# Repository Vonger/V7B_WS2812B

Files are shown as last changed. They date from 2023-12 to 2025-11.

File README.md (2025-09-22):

### Compile Firmware
1. download wch riscv toolchain from its offical site(http://www.mounriver.com/download, select Linux).
2. call **make** to compile the firmware.
3. call **make flash** to upload firmware to device.(hardware requires WCH-LinkE, PD1 to SWDIO)
4. call **make test** to create the local test application.
5. run test, check result on dashboard.

note: IS31FL3731 compatible mode register address only use 1bytes, so max supported LEDs are 72 RGB LEDs(or 216 single color LEDs). Not compatible mode has two bytes for address, so max supported LEDs are 512 RGB LEDs or more(depends on the memory to buffer the LED data)

- ws2812b.is31.bin: this is compatible IS31FL3731 firmware.
- ws2812b.full.bin: this is not compatible but can use all ws2812b in line firmware.

### Link

 - Compile in Ubuntu 22.04
 - WCH CH32V003 RISCV toolchain: http://www.mounriver.com/download => Linux => MRS_Toolchain_Linux_x64_VX.XX.tar.xz
 - install libjlink0 for openocd(sudo apt install libjlink0).

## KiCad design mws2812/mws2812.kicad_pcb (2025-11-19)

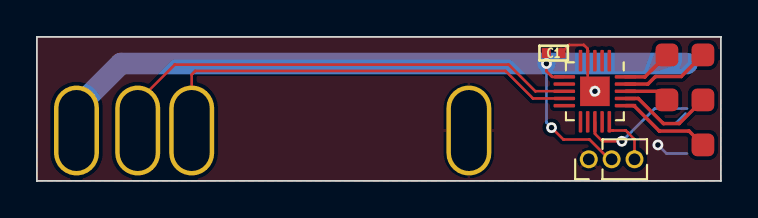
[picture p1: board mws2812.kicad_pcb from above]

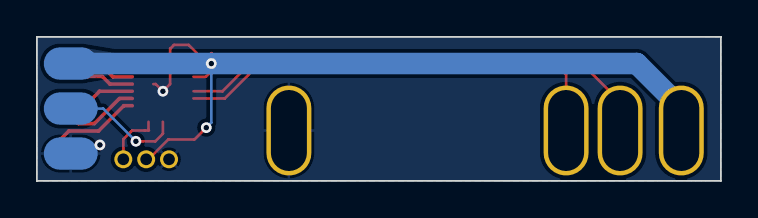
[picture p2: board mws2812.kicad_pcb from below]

Board: 2 copper layers, 38.0 x 8.0 mm, 15 parts (7 on the bottom side), 11 nets.

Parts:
C1: 100nF; 0402C
J1: Conn_01x01; TestPoint_Hole_4.0x2.0mm
J2: Conn_01x03_Socket; PinHeader_1x03_P1.27mm_Vertical
J3, J4, J5: Conn_01x01; TestPoint_Pad_3.0x2.0mm
J6, J7, J8: Conn_01x01; TestPoint_Hole_5.0x2.5mm
J9, J10, J11, J12, J13: Conn_01x01_Socket; TestPoint_Pad_D1.0mm
U3: CH32V003F4U6; QFN-20-1EP_3x3mm_P0.4mm_EP1.65x1.65mm

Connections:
+5V: C1.1, J1.1, J2.2, J5.1, U3.6 (VDD)
DEBUG: J2.3, U3.15 (PD1)
DOUT: J4.1, U3.13 (PC6)
GND: C1.2, J2.1, J3.1, J8.1, U3.4 (VSS), U3.21 (GND)
PD2: J9.1, U3.16 (PD2)
PD3: J10.1, U3.17 (PD3)
PD4: J11.1, U3.18 (PD4)
PD5: J12.1, U3.19 (PD5)
PD6: J13.1, U3.20 (PD6)
SCK: J7.1, U3.9 (PC2)
SDA: J6.1, U3.8 (PC1)

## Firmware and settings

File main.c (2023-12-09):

#include <stdint.h>
#include <ch32v00x.h>

// IS31FL3731_COMPATIBLE:
//     this mode uses 8bit reg address, allows pages(but ignores them)
//     and is compatible with IS31FL3731 register of LED colors.

// convert one 8bit to 32bits.
// 0 code 0.33us/H, 1us/L, 0x08/0b1000
// 1 code 0.66us/H, 0.66us/L, 0x0c/0b1100
// reset 50us/L, 160bits, 50 bytes of SPI around 120us.
#define SPI_RESET_COUNT     50

#ifdef IS31FL3731_COMPATIBLE
#define I2C_ADDRESS         0x74
#define WS2812_MAX_LEDS     72
volatile static uint8_t i2c_page;
#else
#define I2C_ADDRESS         0x74
#define WS2812_MAX_LEDS     512
#endif

volatile static uint8_t cid = SPI_RESET_COUNT;
volatile static uint16_t pid;
volatile static uint8_t pixel[WS2812_MAX_LEDS * 3];
volatile static uint16_t i2c_flag, i2c_reg;
const uint8_t pixel_map[4] = {0x88, 0x8c, 0xc8, 0xcc};

INTERRUPT void SPI1_IRQHandler(void)
{
    if (SPI_I2S_GetITStatus(SPI1, SPI_I2S_IT_TXE)) {
        // color id range [0:3]: we send color by bit.
        // color id range [4:84]: we send zero only as reset.
        if (cid < 4) {
            SPI1->DATAR = pixel_map[(pixel[pid] >> (cid << 1)) & 3];

            // one color has send to end, move to next color.
            if (cid == 0) {
                // if exceed the array size, turn back to begin of the pixels.
                if (++pid >= sizeof(pixel)) {
                    pid = 0;
                    // we need to send reset to leds to show colors.
                    cid = SPI_RESET_COUNT;
                } else {
                    // rearm the color id to send next color.
                    cid = 4;
                }
            }
        } else {
            // reset mode, we send two 0 bits only.
            SPI1->DATAR = 0;
        }

        cid--;
    }
}

INTERRUPT void I2C1_EV_IRQHandler(void)
{
    if (I2C_GetFlagStatus(I2C1, I2C_FLAG_ADDR)) {
        (volatile void)(I2C1->STAR2); // read to clear flag.
        // get address, new transfer begin.
        i2c_reg = i2c_flag = 0;
    } else if (I2C_GetFlagStatus(I2C1, I2C_FLAG_RXNE)) {
#ifdef IS31FL3731_COMPATIBLE
        if (i2c_flag == 0) {
            i2c_reg = I2C_ReceiveData(I2C1);
            i2c_flag++;
        } else if(i2c_reg == 0xfd) {
            i2c_page = I2C_ReceiveData(I2C1);
        } else if (i2c_page == 0) {
            // WS2812 is GRB, but IS31 is RGB, need to convert.
            uint8_t reg;
            switch (i2c_reg % 3) {
            case 0: reg = i2c_reg + 1; break;
            case 1: reg = i2c_reg - 1; break;
            case 2: reg = i2c_reg; break;
            }
            // offset with IS31 start address.
            if (i2c_reg >= 0x24) {
                pixel[reg - 0x24] = I2C_ReceiveData(I2C1);
            } else {
                // receive but ignore.
                I2C_ReceiveData(I2C1);
            }
            i2c_reg++;
        } else {
            // not page 0, read and ignore to avoid block.
            I2C_ReceiveData(I2C1);
        }
#else
        switch (i2c_flag) {
        case 0:   // receive register address high byte.
            i2c_reg |= (uint16_t)I2C_ReceiveData(I2C1) << 8;
            i2c_flag++;
            break;
        case 1:   // receive register address low byte.
            i2c_reg |= (uint16_t)I2C_ReceiveData(I2C1);
            i2c_flag++;
            break;
        default:
            if (i2c_reg < sizeof(pixel)) {
                pixel[i2c_reg++] = I2C_ReceiveData(I2C1);
            } else {
                I2C_ReceiveData(I2C1);
            }
            break;
        }
#endif

    } else if (I2C_GetFlagStatus(I2C1, I2C_FLAG_TXE)) {
        I2C_SendData(I2C1, i2c_reg < sizeof(pixel) ? pixel[i2c_reg++] : 0x00);
    } else if (I2C_GetFlagStatus(I2C1, I2C_FLAG_STOPF)) {
        I2C1->CTLR1 &= I2C1->CTLR1;
    }
}

void spi_init(void)
{
    GPIO_InitTypeDef GPIO_InitStructure;
    SPI_InitTypeDef SPI_InitStructure;
    NVIC_InitTypeDef NVIC_InitStructure;

    RCC_APB2PeriphClockCmd(RCC_APB2Periph_GPIOC, ENABLE);
    RCC_APB2PeriphClockCmd(RCC_APB2Periph_SPI1, ENABLE);

    // WS2812B => PC6
    GPIO_InitStructure.GPIO_Pin = GPIO_Pin_6;
    GPIO_InitStructure.GPIO_Mode = GPIO_Mode_AF_PP;
    GPIO_InitStructure.GPIO_Speed = GPIO_Speed_50MHz;
    GPIO_Init(GPIOC, &GPIO_InitStructure);

    // SPI output data speed = 48M / 16 = 3M
    SPI_InitStructure.SPI_Direction = SPI_Direction_1Line_Tx;
    SPI_InitStructure.SPI_Mode = SPI_Mode_Master;
    SPI_InitStructure.SPI_DataSize = SPI_DataSize_8b;
    SPI_InitStructure.SPI_CPOL = SPI_CPOL_High;
    SPI_InitStructure.SPI_CPHA = SPI_CPHA_1Edge;
    SPI_InitStructure.SPI_NSS = SPI_NSS_Soft;
    SPI_InitStructure.SPI_BaudRatePrescaler = SPI_BaudRatePrescaler_16;
    SPI_InitStructure.SPI_FirstBit = SPI_FirstBit_MSB;
    SPI_InitStructure.SPI_CRCPolynomial = 7;
    SPI_Init(SPI1, &SPI_InitStructure);

    NVIC_InitStructure.NVIC_IRQChannel = SPI1_IRQn;
    NVIC_InitStructure.NVIC_IRQChannelPreemptionPriority = 0;
    NVIC_InitStructure.NVIC_IRQChannelSubPriority = 0;
    NVIC_InitStructure.NVIC_IRQChannelCmd = ENABLE;
    NVIC_Init(&NVIC_InitStructure);

    SPI_I2S_ITConfig(SPI1, SPI_I2S_IT_TXE, ENABLE);
    SPI_Cmd(SPI1, ENABLE);
}

void i2c_init(void)
{
    GPIO_InitTypeDef  GPIO_InitStructure;
    I2C_InitTypeDef   I2C_InitTSturcture;
    NVIC_InitTypeDef  NVIC_InitStructure;

    RCC_APB2PeriphClockCmd(RCC_APB2Periph_GPIOC, ENABLE);
    RCC_APB2PeriphClockCmd(RCC_APB2Periph_AFIO, ENABLE);
    RCC_APB1PeriphClockCmd(RCC_APB1Periph_I2C1, ENABLE);

    // I2CDAT => PC1, I2CCLK => PC2
    GPIO_InitStructure.GPIO_Pin = GPIO_Pin_1 | GPIO_Pin_2;
    GPIO_InitStructure.GPIO_Mode = GPIO_Mode_AF_OD;
    GPIO_InitStructure.GPIO_Speed = GPIO_Speed_50MHz;
    GPIO_Init(GPIOC, &GPIO_InitStructure);

    I2C_InitTSturcture.I2C_ClockSpeed = 400000;
    I2C_InitTSturcture.I2C_Mode = I2C_Mode_I2C;
    I2C_InitTSturcture.I2C_DutyCycle = I2C_DutyCycle_2;
    I2C_InitTSturcture.I2C_Ack = I2C_Ack_Enable;
    I2C_InitTSturcture.I2C_AcknowledgedAddress = I2C_AcknowledgedAddress_7bit;
    I2C_InitTSturcture.I2C_OwnAddress1 = I2C_ADDRESS << 1;
    I2C_Init(I2C1, &I2C_InitTSturcture);

    NVIC_InitStructure.NVIC_IRQChannel = I2C1_EV_IRQn;
    NVIC_InitStructure.NVIC_IRQChannelPreemptionPriority = 0;
    // subpriority set to 8, for group 0 to enable interrupt preemption.
    // enable this or WS2812B data will have wrong timing caused flicker.
    NVIC_InitStructure.NVIC_IRQChannelSubPriority = 8;
    NVIC_InitStructure.NVIC_IRQChannelCmd = ENABLE;
    NVIC_Init(&NVIC_InitStructure);

    I2C_ITConfig(I2C1, I2C_IT_BUF | I2C_IT_EVT, ENABLE);
    I2C_Cmd(I2C1, ENABLE);
}

int main(void)
{
    SystemCoreClockUpdate();
    Delay_Init();

    spi_init();
    i2c_init();

#ifdef UNITTEST_LED_BREATH
    uint8_t count = 0, dir = 0, color = 0;
    while (1) {
        for(int i = color; i < sizeof(pixel); i += 3)
            pixel[i] = count;
        Delay_Ms(10);

        if (dir) {
            if (++count == 0) {
                dir = 0;
                count = 254;
            }
        } else {
            if (--count == 0) {
                dir = 1;
                if (++color >= 3)
                    color = 0;
            }
        }
    }
#else
    while (1);
#endif
}

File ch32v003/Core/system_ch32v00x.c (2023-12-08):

/********************************** (C) COPYRIGHT *******************************
 * File Name          : system_ch32v00x.c
 * Author             : WCH
 * Version            : V1.0.0
 * Date               : 2022/08/08
 * Description        : CH32V00x Device Peripheral Access Layer System Source File.
*********************************************************************************
* Copyright (c) 2021 Nanjing Qinheng Microelectronics Co., Ltd.
* Attention: This software (modified or not) and binary are used for 
* microcontroller manufactured by Nanjing Qinheng Microelectronics.
*******************************************************************************/
#include <ch32v00x.h>

/* 
* Uncomment the line corresponding to the desired System clock (SYSCLK) frequency (after 
* reset the HSI is used as SYSCLK source).
* If none of the define below is enabled, the HSI is used as System clock source. 
*/

//#define SYSCLK_FREQ_8MHz_HSI    8000000
//#define SYSCLK_FREQ_24MHZ_HSI   HSI_VALUE
//#define SYSCLK_FREQ_48MHZ_HSI   48000000
//#define SYSCLK_FREQ_8MHz_HSE    8000000
//#define SYSCLK_FREQ_24MHz_HSE   HSE_VALUE
//#define SYSCLK_FREQ_48MHz_HSE   48000000

/* Clock Definitions */
#ifdef SYSCLK_FREQ_8MHz_HSI
  uint32_t SystemCoreClock         = SYSCLK_FREQ_8MHz_HSI;          /* System Clock Frequency (Core Clock) */
#elif defined SYSCLK_FREQ_24MHZ_HSI
  uint32_t SystemCoreClock         = SYSCLK_FREQ_24MHZ_HSI;        /* System Clock Frequency (Core Clock) */
#elif defined SYSCLK_FREQ_48MHZ_HSI
  uint32_t SystemCoreClock         = SYSCLK_FREQ_48MHZ_HSI;        /* System Clock Frequency (Core Clock) */
#elif defined SYSCLK_FREQ_8MHz_HSE
  uint32_t SystemCoreClock         = SYSCLK_FREQ_8MHz_HSE;         /* System Clock Frequency (Core Clock) */
#elif defined SYSCLK_FREQ_24MHz_HSE
  uint32_t SystemCoreClock         = SYSCLK_FREQ_24MHz_HSE;        /* System Clock Frequency (Core Clock) */
#elif defined SYSCLK_FREQ_48MHz_HSE
  uint32_t SystemCoreClock         = SYSCLK_FREQ_48MHz_HSE;        /* System Clock Frequency (Core Clock) */
#else
  uint32_t SystemCoreClock         = HSI_VALUE;
#endif

__I uint8_t AHBPrescTable[16] = {1, 2, 3, 4, 5, 6, 7, 8, 1, 2, 3, 4, 5, 6, 7, 8};


/* system_private_function_proto_types */
static void SetSysClock(void);

#ifdef SYSCLK_FREQ_8MHz_HSI
  static void SetSysClockTo_8MHz_HSI(void);
#elif defined SYSCLK_FREQ_24MHZ_HSI
  static void SetSysClockTo_24MHZ_HSI(void);
#elif defined SYSCLK_FREQ_48MHZ_HSI
  static void SetSysClockTo_48MHZ_HSI(void);
#elif defined SYSCLK_FREQ_8MHz_HSE
  static void SetSysClockTo_8MHz_HSE(void);
#elif defined SYSCLK_FREQ_24MHz_HSE
  static void SetSysClockTo_24MHz_HSE(void);
#elif defined SYSCLK_FREQ_48MHz_HSE
  static void SetSysClockTo_48MHz_HSE(void);
#endif


/*********************************************************************
 * @fn      SystemInit
 *
 * @brief   Setup the microcontroller system Initialize the Embedded Flash Interface,
 *        the PLL and update the SystemCoreClock variable.
 *
 * @return  none
 */
void SystemInit (void)
{
  RCC->CTLR |= (uint32_t)0x00000001;
  RCC->CFGR0 &= (uint32_t)0xFCFF0000;
  RCC->CTLR &= (uint32_t)0xFEF6FFFF;
  RCC->CTLR &= (uint32_t)0xFFFBFFFF;
  RCC->CFGR0 &= (uint32_t)0xFFFEFFFF;
  RCC->INTR = 0x009F0000;

  SetSysClock();
}


/*********************************************************************
 * @fn      SystemCoreClockUpdate
 *
 * @brief   Update SystemCoreClock variable according to Clock Register Values.
 *
 * @return  none
 */
void SystemCoreClockUpdate (void)
{
    uint32_t tmp = 0, pllsource = 0;

    tmp = RCC->CFGR0 & RCC_SWS;

    switch (tmp)
    {
        case 0x00:
            SystemCoreClock = HSI_VALUE;
            break;
        case 0x04:
            SystemCoreClock = HSE_VALUE;
            break;
        case 0x08:
            pllsource = RCC->CFGR0 & RCC_PLLSRC;
            if (pllsource == 0x00)
            {
                SystemCoreClock = HSI_VALUE * 2;
            }
            else
            {
                SystemCoreClock = HSE_VALUE * 2;
            }
            break;
        default:
            SystemCoreClock = HSI_VALUE;
            break;
    }

    tmp = AHBPrescTable[((RCC->CFGR0 & RCC_HPRE) >> 4)];

    if(((RCC->CFGR0 & RCC_HPRE) >> 4) < 8)
    {
        SystemCoreClock /= tmp;
    }
    else
    {
        SystemCoreClock >>= tmp;
    }
}


/*********************************************************************
 * @fn      SetSysClock
 *
 * @brief   Configures the System clock frequency, HCLK, PCLK2 and PCLK1 prescalers.
 *
 * @return  none
 */
static void SetSysClock(void)
{
RCC->APB2PCENR |= RCC_APB2Periph_GPIOD;
GPIOD->CFGLR&=(~0xF0);
GPIOD->CFGLR|=0x80;
GPIOD->BSHR =0x2;
#ifdef SYSCLK_FREQ_8MHz_HSI
    SetSysClockTo_8MHz_HSI();
#elif defined SYSCLK_FREQ_24MHZ_HSI
    SetSysClockTo_24MHZ_HSI();
#elif defined SYSCLK_FREQ_48MHZ_HSI
    SetSysClockTo_48MHZ_HSI();
#elif defined SYSCLK_FREQ_8MHz_HSE
    SetSysClockTo_8MHz_HSE();
#elif defined SYSCLK_FREQ_24MHz_HSE
    SetSysClockTo_24MHz_HSE();
#elif defined SYSCLK_FREQ_48MHz_HSE
    SetSysClockTo_48MHz_HSE();
#endif
 
 /* If none of the define above is enabled, the HSI is used as System clock.
  * source (default after reset) 
	*/ 
}


#ifdef SYSCLK_FREQ_8MHz_HSI

/*********************************************************************
 * @fn      SetSysClockTo_8MHz_HSI
 *
 * @brief   Sets HSE as System clock source and configure HCLK, PCLK2 and PCLK1 prescalers.
 *
 * @return  none
 */
static void SetSysClockTo_8MHz_HSI(void)
{
    /* Flash 0 wait state */
    FLASH->ACTLR &= (uint32_t)((uint32_t)~FLASH_ACTLR_LATENCY);
    FLASH->ACTLR |= (uint32_t)FLASH_ACTLR_LATENCY_0;

    /* HCLK = SYSCLK = APB1 */
    RCC->CFGR0 |= (uint32_t)RCC_HPRE_DIV3;
}

#elif defined SYSCLK_FREQ_24MHZ_HSI

/*********************************************************************
 * @fn      SetSysClockTo_24MHZ_HSI
 *
 * @brief   Sets System clock frequency to 24MHz and configure HCLK, PCLK2 and PCLK1 prescalers.
 *
 * @return  none
 */
static void SetSysClockTo_24MHZ_HSI(void)
{
    /* Flash 0 wait state */
    FLASH->ACTLR &= (uint32_t)((uint32_t)~FLASH_ACTLR_LATENCY);
    FLASH->ACTLR |= (uint32_t)FLASH_ACTLR_LATENCY_0;

    /* HCLK = SYSCLK = APB1 */
    RCC->CFGR0 |= (uint32_t)RCC_HPRE_DIV1;
}


#elif defined SYSCLK_FREQ_48MHZ_HSI
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

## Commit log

2023-11-04 first version for i2c ws2812.
2023-11-05 fix second led flash sometimes because of the reset too short.
    [main.c]
2023-11-05 update max support LED to 512.
2023-11-23 spi use one pin only PC6.
2023-11-25 update unit test to avoid flash.
    [main.c]
2023-11-27 set spi interrupt higher than i2c.
2023-11-27 reduce led number.
2023-11-29 fix interrupt priority casued led flash.
    [main.c]
2023-11-29 final solution of interrupt flash issue.
    [main.c]
2023-12-08 update reset time to compatible more ws2812b.
    [main.c]
2023-12-09 fix i2c reg byte order.
    [main.c]
2023-12-09 fix IS31FL3731 compatible mode.
    [main.c]
2023-12-09 add led test code.
2023-12-09 update LED flash speed.
2024-01-13 change test output file name to ledtest.
2024-04-18 fix warning and increase led speed.
    [test.c]
2025-10-13 update test to support new LED mode.
2025-10-13 add usleep for enough reset time.
    [test.c]
2025-11-19 add driver board sch and pcb.
    [mws2812.kicad_pcb, mws2812.kicad_sch]
